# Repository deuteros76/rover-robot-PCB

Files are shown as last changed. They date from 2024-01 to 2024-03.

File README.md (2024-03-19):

# rover-robot-PCB

## Description

This is a multipurpose PCB for Arduino projects using ESP32. The main objective is to create a board to make robots easily but it can be used also to create different types of DIY projects such as a weather station. 

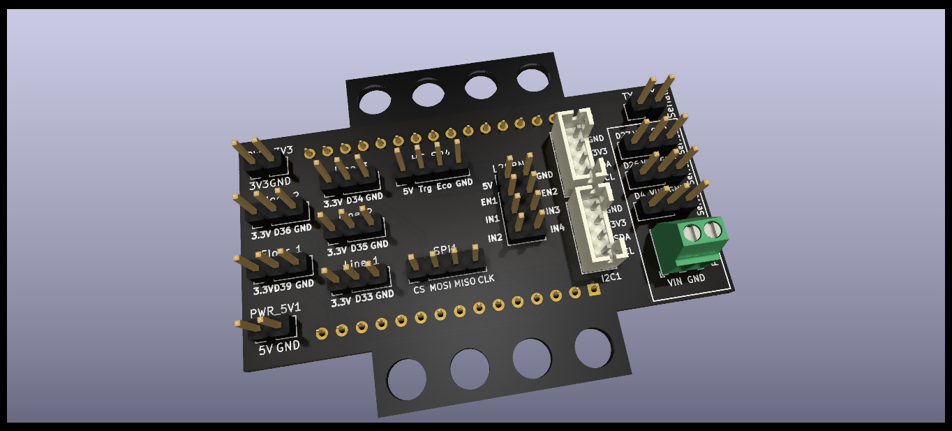
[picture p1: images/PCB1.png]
Rover robot-pcb1


It could be programmed using PlatformIO, Pictoblox, Arduinoblocks, etc. Then, it can be mounted in a structure made of universal/compatible toy bricks. This makes this board a good option for educational purposes with kids.

Example board case (https://youtu.be/dpZD5vXgrrg?si=Fezu1EV8ZPVySiNU)

Currently I'm working on a remote controlled vehicle programmed in Pictoblox. I'm constantly modifying the design and you can follow the updates in my X account: 

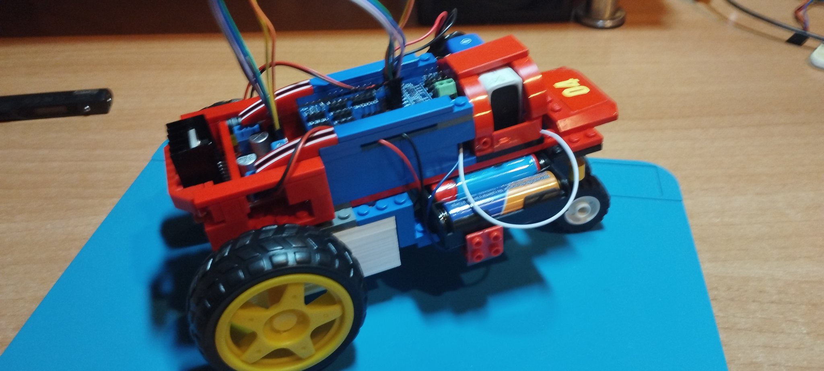
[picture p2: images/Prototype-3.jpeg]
Example board case (https://x.com/deuteros/status/1769453724865282358?s=20)


## Future

This repository will contain the latest version of the PCB and soon, examples of source code for robots, remote controlled vehicles and perhaps other kind of inventions.

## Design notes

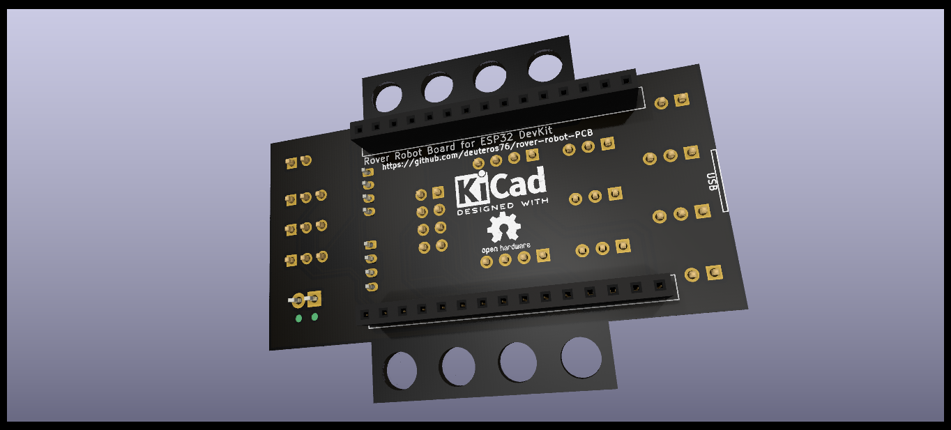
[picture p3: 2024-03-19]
images/PCB2.png

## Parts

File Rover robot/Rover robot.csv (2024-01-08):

# | Reference | Qty | Value | Footprint | DNP
1 | 3v3_Power1 | 1 | Conn_02x02_Odd_Even | ESP32_DevKit_V1_DOIT:esp32_devkit_v1_doit_simplified
2 | 5V_Power1 | 1 | Conn_02x02_Odd_Even | Connector_PinHeader_2.54mm:PinHeader_2x02_P2.54mm_Vertical
3 | ESP32_DevKit_V1_DOIT1 | 1 | ESP32_DevKit_V1_DOIT | ESP32_DevKit_V1_DOIT:esp32_devkit_v1_doit
4 | Floor_Detector1, Floor_Detector2, Line_Detector1, Line_Detector2, Line_Detector3 | 5 | TCRT5000 | Connector_PinHeader_2.54mm:PinHeader_1x03_P2.54mm_Vertical
5 | HC_SR4 | 1 | HC SR04 | Connector_PinHeader_2.54mm:PinHeader_1x04_P2.54mm_Vertical
6 | I2C1 | 1 | I2C | Connector_PinHeader_2.54mm:PinHeader_1x04_P2.54mm_Vertical
7 | J1 | 1 | Serial | Connector_PinHeader_2.54mm:PinHeader_1x02_P2.54mm_Vertical
8 | J2 | 1 | Screw_Terminal_01x02 | TerminalBlock_Phoenix:TerminalBlock_Phoenix_MPT-0,5-2-2.54_1x02_P2.54mm_Horizontal
9 | L298N1 | 1 | L298N | Connector_PinHeader_2.54mm:PinHeader_2x04_P2.54mm_Vertical
10 | Servo1, Servo2, Servo3 | 3 | Conn_01x03_Pin | Connector_PinHeader_2.54mm:PinHeader_1x03_P2.54mm_Vertical

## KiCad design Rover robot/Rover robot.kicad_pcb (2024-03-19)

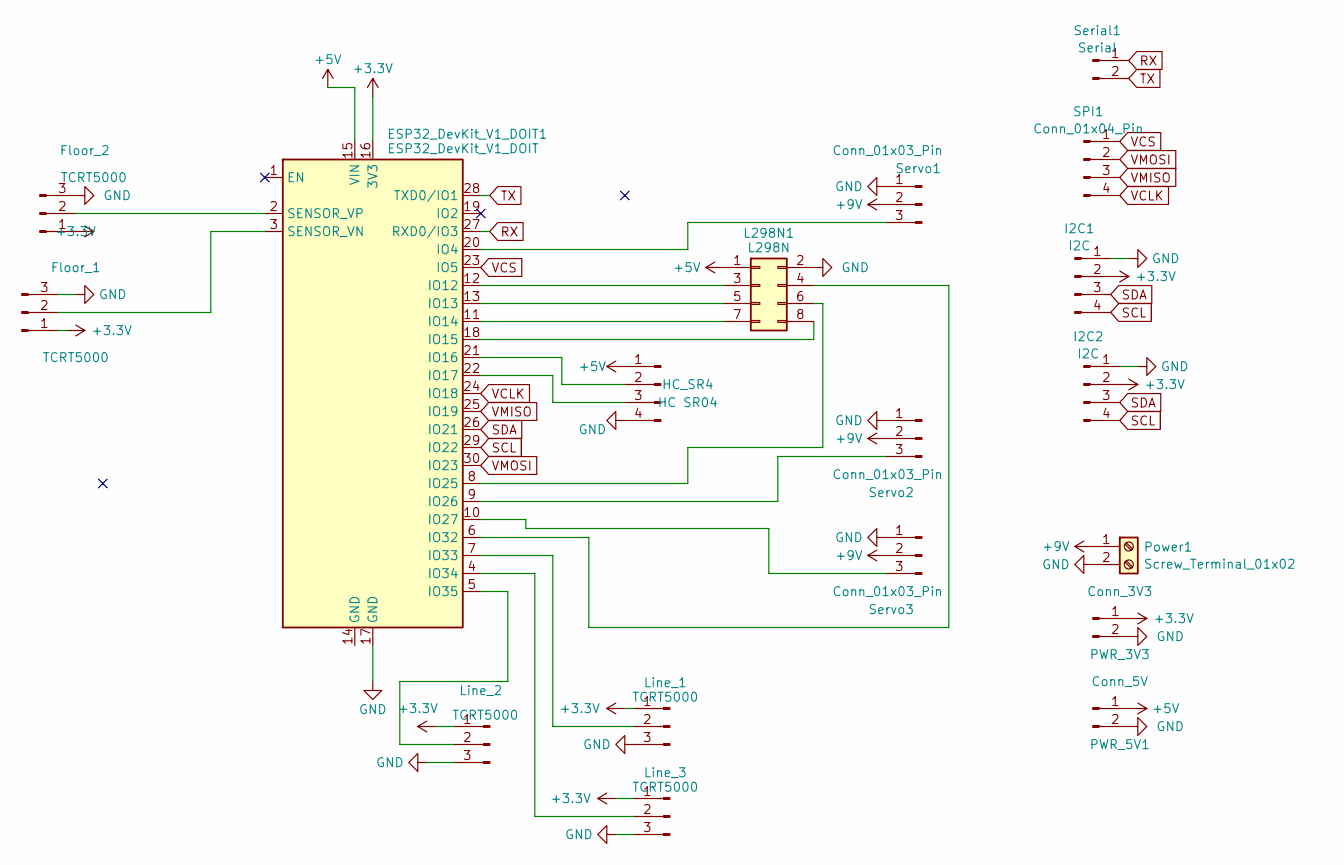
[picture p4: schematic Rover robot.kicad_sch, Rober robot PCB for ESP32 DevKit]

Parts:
ESP32_DevKit_V1_DOIT1: ESP32_DevKit_V1_DOIT; esp32_devkit_v1_doit_simplified
Floor_1, Floor_2: TCRT5000; PinHeader_1x03_P2.54mm_Vertical
HC_SR4: HC SR04; PinHeader_1x04_P2.54mm_Vertical
I2C1, I2C2: I2C; JST_PH_B4B-PH-K_1x04_P2.00mm_Vertical
L298N1: L298N; PinHeader_2x04_P2.54mm_Vertical
Line_1, Line_2, Line_3: TCRT5000; PinHeader_1x03_P2.54mm_Vertical
PWR_3V3: Conn_3V3; PinHeader_1x02_P2.54mm_Vertical
PWR_5V1: Conn_5V; PinHeader_1x02_P2.54mm_Vertical
Power1: Screw_Terminal_01x02; TerminalBlock_Phoenix_MPT-0,5-2-2.54_1x02_P2.54mm_Horizontal
SPI1: Conn_01x04_Pin; PinHeader_1x04_P2.54mm_Vertical
Serial1: Serial; PinHeader_1x02_P2.54mm_Vertical
Servo1, Servo2, Servo3: Conn_01x03_Pin; PinHeader_1x03_P2.54mm_Vertical

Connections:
+3.3V: ESP32_DevKit_V1_DOIT1.16 (3V3), Floor_1.1, Floor_2.1, I2C1.2, I2C2.2, Line_1.1, Line_2.1, Line_3.1, PWR_3V3.1
+5V: ESP32_DevKit_V1_DOIT1.15 (VIN), HC_SR4.1 (5v), L298N1.1, PWR_5V1.1
+9V: Power1.1, Servo1.2, Servo2.2, Servo3.2
GND: ESP32_DevKit_V1_DOIT1.17 (GND), Floor_1.3, Floor_2.3, HC_SR4.4 (GND), I2C1.1, I2C2.1, L298N1.2, Line_1.3, Line_2.3, Line_3.3, PWR_3V3.2, PWR_5V1.2, Power1.2, Servo1.1, Servo2.1, Servo3.1
unnamed: ESP32_DevKit_V1_DOIT1.20 (IO4), Servo1.3
unnamed: ESP32_DevKit_V1_DOIT1.12 (IO12), L298N1.3
unnamed: ESP32_DevKit_V1_DOIT1.13 (IO13), L298N1.5
unnamed: ESP32_DevKit_V1_DOIT1.11 (IO14), L298N1.7
unnamed: ESP32_DevKit_V1_DOIT1.18 (IO15), L298N1.8
unnamed: ESP32_DevKit_V1_DOIT1.21 (IO16), HC_SR4.2
unnamed: ESP32_DevKit_V1_DOIT1.22 (IO17), HC_SR4.3
unnamed: ESP32_DevKit_V1_DOIT1.8 (IO25), L298N1.6
unnamed: ESP32_DevKit_V1_DOIT1.9 (IO26), Servo2.3
unnamed: ESP32_DevKit_V1_DOIT1.10 (IO27), Servo3.3
unnamed: ESP32_DevKit_V1_DOIT1.6 (IO32), L298N1.4
unnamed: ESP32_DevKit_V1_DOIT1.7 (IO33), Line_1.2
unnamed: ESP32_DevKit_V1_DOIT1.4 (IO34), Line_3.2
unnamed: ESP32_DevKit_V1_DOIT1.5 (IO35), Line_2.2
unnamed: ESP32_DevKit_V1_DOIT1.3 (SENSOR_VN), Floor_1.2
unnamed: ESP32_DevKit_V1_DOIT1.2 (SENSOR_VP), Floor_2.2
RX: ESP32_DevKit_V1_DOIT1.27 (RXD0/IO3), Serial1.1
SCL: ESP32_DevKit_V1_DOIT1.29 (IO22), I2C1.4, I2C2.4
SDA: ESP32_DevKit_V1_DOIT1.26 (IO21), I2C1.3, I2C2.3
TX: ESP32_DevKit_V1_DOIT1.28 (TXD0/IO1), Serial1.2
VCLK: ESP32_DevKit_V1_DOIT1.24 (IO18), SPI1.4
VCS: ESP32_DevKit_V1_DOIT1.23 (IO5), SPI1.1
VMISO: ESP32_DevKit_V1_DOIT1.25 (IO19), SPI1.3
VMOSI: ESP32_DevKit_V1_DOIT1.30 (IO23), SPI1.2

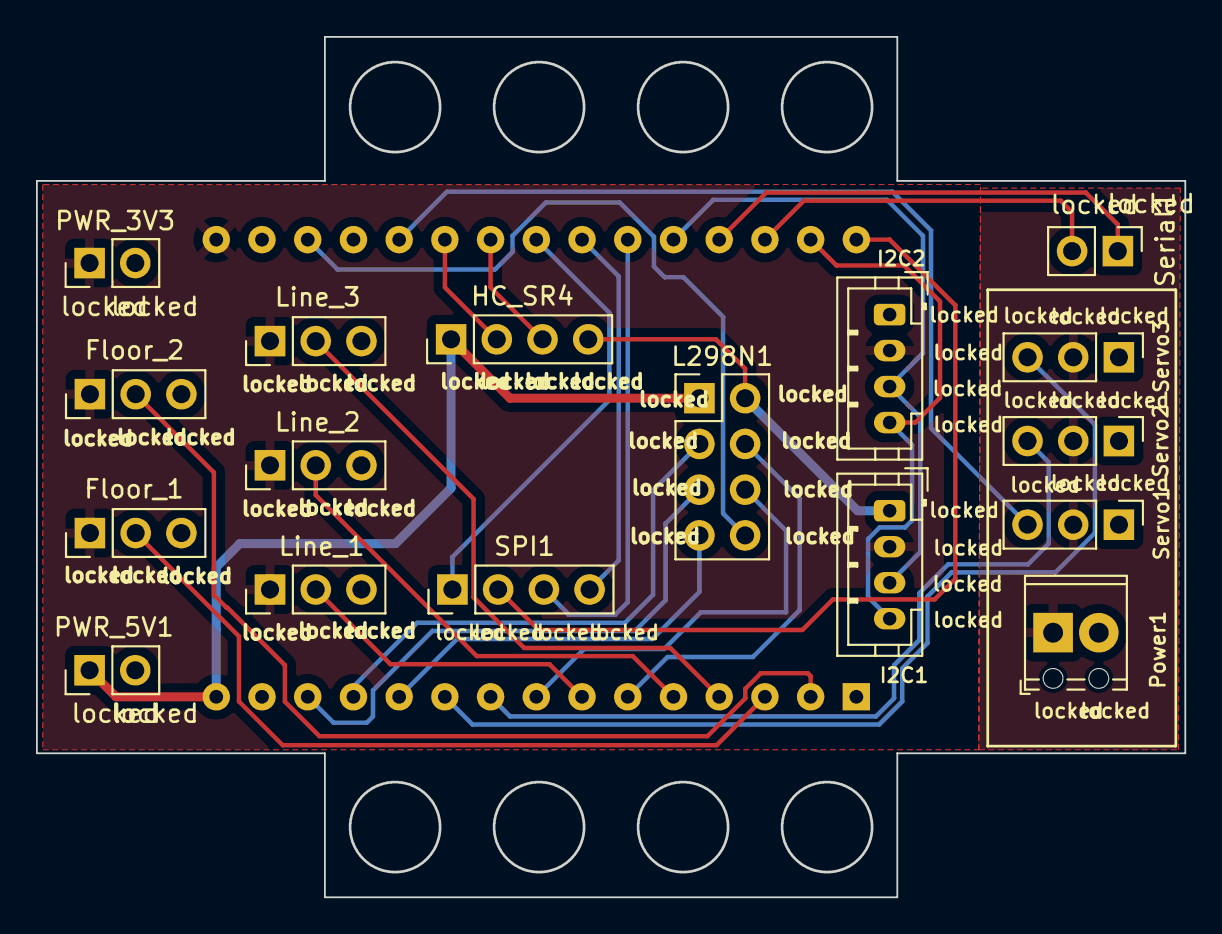
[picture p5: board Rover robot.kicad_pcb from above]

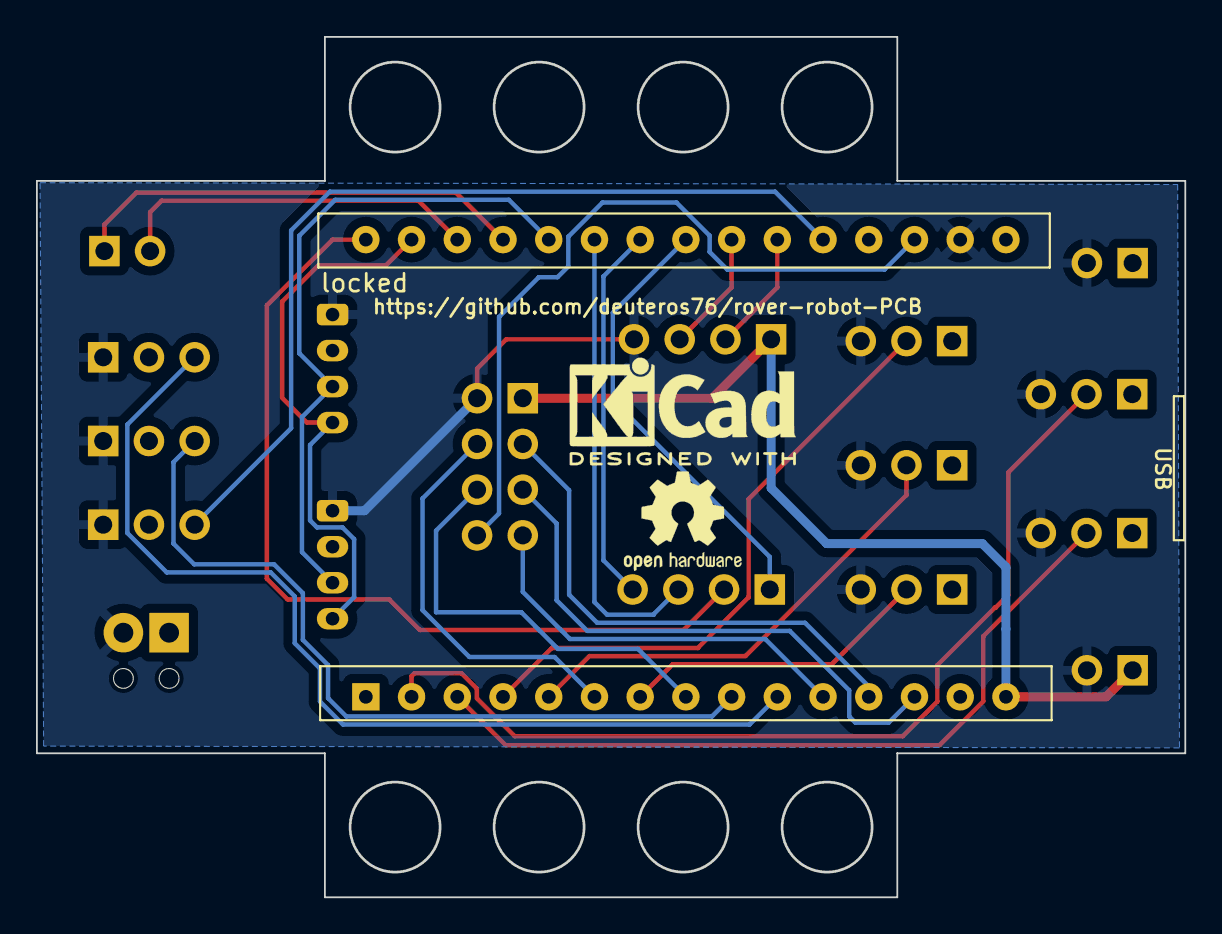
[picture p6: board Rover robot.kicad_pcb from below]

Board: 2 copper layers, 63.8 x 47.8 mm, 19 parts (2 on the bottom side), 28 nets.

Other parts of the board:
KiCad: KiCad-Logo2_5mm_SilkScreen

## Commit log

2024-01-02 Feat: frist commit. First version of the PCB
    [Rover robot.csv, Rover robot.kicad_pcb, Rover robot.kicad_sch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]
2024-01-08 feat: new brick compatible size
    [Rover robot.csv, Rover robot.kicad_pcb, Rover robot.kicad_sch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]
2024-02-18 Produced version of the first brick variant
    [Rover robot.kicad_pcb]
2024-03-19 refactor: minor changes
    [Rover robot.kicad_pcb, Rover robot.kicad_sch]
